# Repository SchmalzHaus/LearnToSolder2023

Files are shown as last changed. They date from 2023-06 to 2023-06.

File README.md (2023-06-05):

# LearnToSolder2018

Learn To Solder 2018 Board, assembled

## Introduction

For the past couple years, Deanna Schmalz has designed a simple circuit board which we then use to teach learn to solder classes. We  make enough boards and buy enough parts to teach all of the 4th graders at Glen Lake Elementary School in Minnetonka Minnesota, USA how to solder.

This site contains all of the information related to this year's Learn To Solder board. If you want to learn more about how to solder, if you want to know what you need to purchase so you can solder at home, or if you want to make more of these boards for yourself or your organization, this site has everything you'll need.

If you want to reach Brian Schmalz (brian@schmalzaus.com) or Deanna (deanna@schmalzhaus.com) to ask us any questions, please do so. 

All text files and designs on this site are Open Source. You are free to use these files and do whatever you wish with them.

## LearnToSolder 2018 Kit Contents

* Qty 1 Circuit Board - with pre-programmed PIC12F1572 CPU soldered on
* Qty 2 Switches
* Qty 2 Switch caps (various colors)
* Qty 2 Red LEDs
* Qty 2 Green LEDs
* Qty 2 Yellow LEDs
* Qty 2 Blue LEDs
* Qty 1 CR2032 Battery Holder
* Qty 1 CR2032 Battery
* Qty 2 random value through hole resistors (for Octopus eyebrows)

## Tools

To solder electronic kits together, you will need (at a minimum)

### Soldering Iron

We do not recommend buying a soldering iron unless it is 'temperature controlled'. This means you get to set the tip temperature with a knob or buttons, and the iron will only heat up as much as it needs to in order to maintain that temperature. Using a non-temp controlled iron has, in our experience, led to lots of frustration and failed kits.

This is the iron we recommend, as we've had great experience with it and it is very inexpensive : [http://www.hobbyking.com/hobbyking/store/__19240__Soldering_Station_with_Adjustable_Heat_Range_US_Warehouse_.html]

You can also by this same type of iron from many other places, including Amazon and Ebay, but the price tends to be a bit higher. Some of the companies listed below under Other Soldering Kits also sell tools like irons.

### Solder

For beginners, we strongly recommend using leaded solder (rather than lead-free). The safety risk is very minimal (just be sure to wash your hands with soap when you are done) and it is far, far easier to get good soldered joints with leaded solder when you're just starting to learn soldering. You can buy leaded electronic solder at many on-line stores like SparkFun [https://www.sparkfun.com/products/9161] or Adafruit [https://www.adafruit.com/products/1886]. Make sure to buy 60/40 or 63/37 (those numbers represent the ratio of tin to lead in the solder) electronic solder - there are other solders out there (like silver solder for jewelry for example) that won't work for electronics.

### Brass Sponge

When you buy your iron, buy a bras sponge if the iron doesn't already come with it. These are much better than the watter sponge that comes with the iron for cleaning the tip of the soldering iron.

### Wire Cutter

All of the companies listed below sell small wire cutters, or you can get them locally at hardware stores too. The best kind is something that will allow you to cut off wires flush with the board - sometimes called 'flush cutters'. For example [https://www.sparkfun.com/products/11952] or [https://www.adafruit.com/products/152]

### Other tools

There are lots of other tools you can get to help you while solder. Third-hands can be very useful. Needle nose pliers, solder suckers, magnifying glasses, solder wick, wire strippers, etc.

## Kit Assembly Process (overview)

There are only a couple steps to assembling this kit, as it is very simple. If you have done soldering before, you can just walk through this overview of the steps to complete your kit. If you want to learn more about how to do the actual soldering of a joint, the following websites and resources will give you plenty of background materials and explanations:

https://learn.sparkfun.com/tutorials/how-to-solder---through-hole-soldering

http://www.howtogeek.com/63630/how-to-use-a-soldering-iron-a-beginners-guide/

https://cdn-learn.adafruit.com/downloads/pdf/adafruit-guide-excellent-soldering.pdf

### Steps:

1. Solder the eight LEDs. Follow the color guide on the circuit board. Long lead (wire) goes into square hole. You sometimes have to wiggle the LEDs a bit to get them to press all the way flat down on the top side of the board due to a thick spot on the LED leads. Bend the leads apart on the back side to keep the LEDs in place as you solder the LED wires on the back side of the board. Clip the excess leads on the back of the board once soldered.

2. Insert the two switches into the board. Make sure all parts go into the board from the top side (with the thick white lines) to the back side. The switches snap down into the board - you sometimes have to press them in hard to get them to snap. But be careful - sometimes the pins come somewhat bent and pressing them down hard will bend them further if all four are not in the holes as you press down. Solder the four pins of each switch on the back side of the board. Snap the two switch caps down on the switches.

3. Insert the battery holder to the front of the board, being careful to align the outline of the battery hold to the white outline on the top of the board (there is a square tab on the battery holder than needs to match up to the square tab part of the outline). While holding the battery holder into the board, flip it over and solder both pins.

4. Insert the two eyebrow resistors. They are not part of the circut but are just for looks. Bend each lead of the reisstor so that the leads go through the board and the resistor sits flush on the board. Solder the leads on the back side of the board and clip excess lead length.

4. Insert the battery into the holder, flat shiny + side up. Press the buttons to see your LEDs light. If you hold down a button, the octopus will display a pattern.

## Other Soldering Kits

There are SO MANY kits available today, it's impossible to list all of them, or even the good ones. If you do a Google search for "electronic soldering kit" you will find lots of them out there. Some are easier than others, and some come with great instructions (and some don't).

We buy a lot of high quality soldering kits from the following on-line companies:

Evil Mad Scientist [http://shop.evilmadscientist.com/]
* Their Boldport Buggy is excellent [http://shop.evilmadscientist.com/]
* The Flickery Flame is a great beginner kit [http://shop.evilmadscientist.com/productsmenu/793]

Spark Fun Electronics [https://www.sparkfun.com/]
* They have a whole catagory of 'kits', some of which are soldering kits [https://www.sparkfun.com/categories/157]
* The SparkFun Simon Says - Through-Hole kit is really fun [https://www.sparkfun.com/products/10547]

Adafruit [https://www.adafruit.com/]
* The Drawdio is quite fun [https://www.adafruit.com/categories/28]
* Their Minty Boost is actually quite useful [https://www.adafruit.com/products/14]

SeeedStudio [http://www.seeedstudio.com/]
* Their 4-Soldering Zoo Kit looks super cute [https://www.seeedstudio.com/item_detail.html?p_id=1950]

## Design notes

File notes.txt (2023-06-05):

LearnToSolder 2018 Notes file

* Use PIC12F1572-I/SN microcontroller (8-pin SOIC SMT part)
* Use 2 push button switches as input
* Can push button switches do wakeup? Or is a SPDT slide switch needed? Looks like the two push buttons can be used to wake up the processor.
* How many LEDs can be chaliplexed? Wikipedia says up to 12 with 4 I/Os.
* Can we use RGB leds? (four pins)
  * Problem - their pins are very close together
* How about 8 LEDs (two each red, green, yellow, blue)?
* Need to add pads for programming/debugging - use 3D printed jig with pogo pins? How about 'snap-on' or 'clip on' to edge of board?

* What is best maximum board size?
  Seeed will do 100mm x 100mm, qt 10 for $4.41. But if qty goes up, price goes up. Order lots of 10s? Does that just increase shipping?

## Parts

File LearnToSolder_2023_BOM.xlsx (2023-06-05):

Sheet: Sheet1
Learn To Solder 2023 Octopus BOM
Qty | Ref | Description | Mfg Part Number | Distributor Part Number | Distributor
1 |  | Linear Voltage Regulator IC Positive Fixed 1 Output 1A SOT-223-4 | LM3940IMP-3.3/NOPB | LM3940IMP-3.3/NOPBCT-ND | Digikey
1 |  | USB-C (USB TYPE-C) USB 2.0 Receptacle Connector 24 (16+8 Dummy) Position Surface Mount, Right Angle; Through Hole | DX07S016JA1R1500 | 670-DX07S016JA1R1500TR-ND | Digikey
 |  | Connector Header Surface Mount, Right Angle 36 position 0.100" (2.54mm) | GEC36SBSN-M89 | S1113E-36-ND | Digikey
 | DO NOT POPULATE

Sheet: Sheet2
Pin | Number | Use | Left | 33 | Need: | 20 for motor drivers | SLEEP
RH2 | 1 | JP2 IO | LATCH |  |  | 6 for MISC | MS1
RH3 | 2 | JP2 IO | DIG_1 |  | Leavs: | 7 spare | MS2
RE1 | 3 | MS2_1 | DIG_2 |  |  |  | PFD
RE0 | 4 | MS1_1 | PRG | RC2 |  |  | ENABLE
RG0 | 5 | DIG_1 | USR_LED | RC1
RG1 | 6 | TX2 | USB_LED | RC0
RG2 | 7 | RX2
RG3 | 8 | DIG_2
MCLR | 9 | MCLR
RG4 | 10 | SPARE1
VSS | 11 | PWR
VDDCORE/VCAP | 12 | PWR
RF7 | 13 | PFD_4
RF6 | 14 | PFD_3
RF5 | 15 | PFD_2
RF4 | 16 | D+
RF3 | 17 | D-
RF2 | 18 | PFD_1
RH7 | 19 | JP2 IO
RH6 | 20 | JP2 IO
RH5 | 21 | JP2 IO
RH4 | 22 | JP2 IO
VUSB | 23 | PWR
ENVREG | 24 | PWR
AVDD | 25 | PWR
AVSS | 26 | PWR
RA3 | 27 | SPARE2
RA2 | 28 | SPARE3
RA1 | 29 | SPARE4
RA0 | 30 | SPARE5
VSS | 31 | PWR
VDDCORE/VCAP | 32 | PWR
RA5 | 33 | SPARE6
RA4 | 34 | LATCH
RC1 | 35 | JP1 IO
RC0 | 36 | JP1 IO
RC6 | 37 | JP1 IO
RC7 | 38 | JP1 IO
RJ4 | 39 | ENABLE_1
RJ5 | 40 | ENABLE_2
RJ6 | 41 | ENABLE_3
RJ7 | 42 | ENABLE_4
RC2 | 43 | JP1 IO
RC3 | 44 | JP1 IO
RC4 | 45 | JP1 IO
RC5 | 46 | JP1 IO
RB7 | 47 | DIR_4
VDD | 48 | PWR
OSC1 | 49 | -
OSC2 | 50 | -
VSS | 51 | PWR
RB6 | 52 | STEP_4
RB5 | 53 | DIR_3
RB4 | 54 | STEP_3
RB3 | 55 | DIR_2
RB2 | 56 | STEP_2
RB1 | 57 | DIR_1
RB0 | 58 | STEP_1
RJ3 | 59 | SLEEP_4
RJ2 | 60 | SLEEP_3
RJ1 | 61 | SLEEP_2
RJ0 | 62 | SLEEP_1
RD7 | 63 | SS
RD6 | 64 | SCK
RD5 | 65 | SDI_IN
RD4 | 66 | SDO_OUT
RD3 | 67 | SPARE7
RD2 | 68 | PRG
RD1 | 69 | USR_LED
VSS | 70 | PWR
VDD | 71 | PWR
RD0 | 72 | USB_LED
RE7 | 73 | MS2_4
RE6 | 74 | MS1_4
RE5 | 75 | MS2_3
RE4 | 76 | MS1_3
RE3 | 77 | MS2_2
RE2 | 78 | MS1_2
RH0 | 79 | JP2 IO
RH1 | 80 | JP2 IO

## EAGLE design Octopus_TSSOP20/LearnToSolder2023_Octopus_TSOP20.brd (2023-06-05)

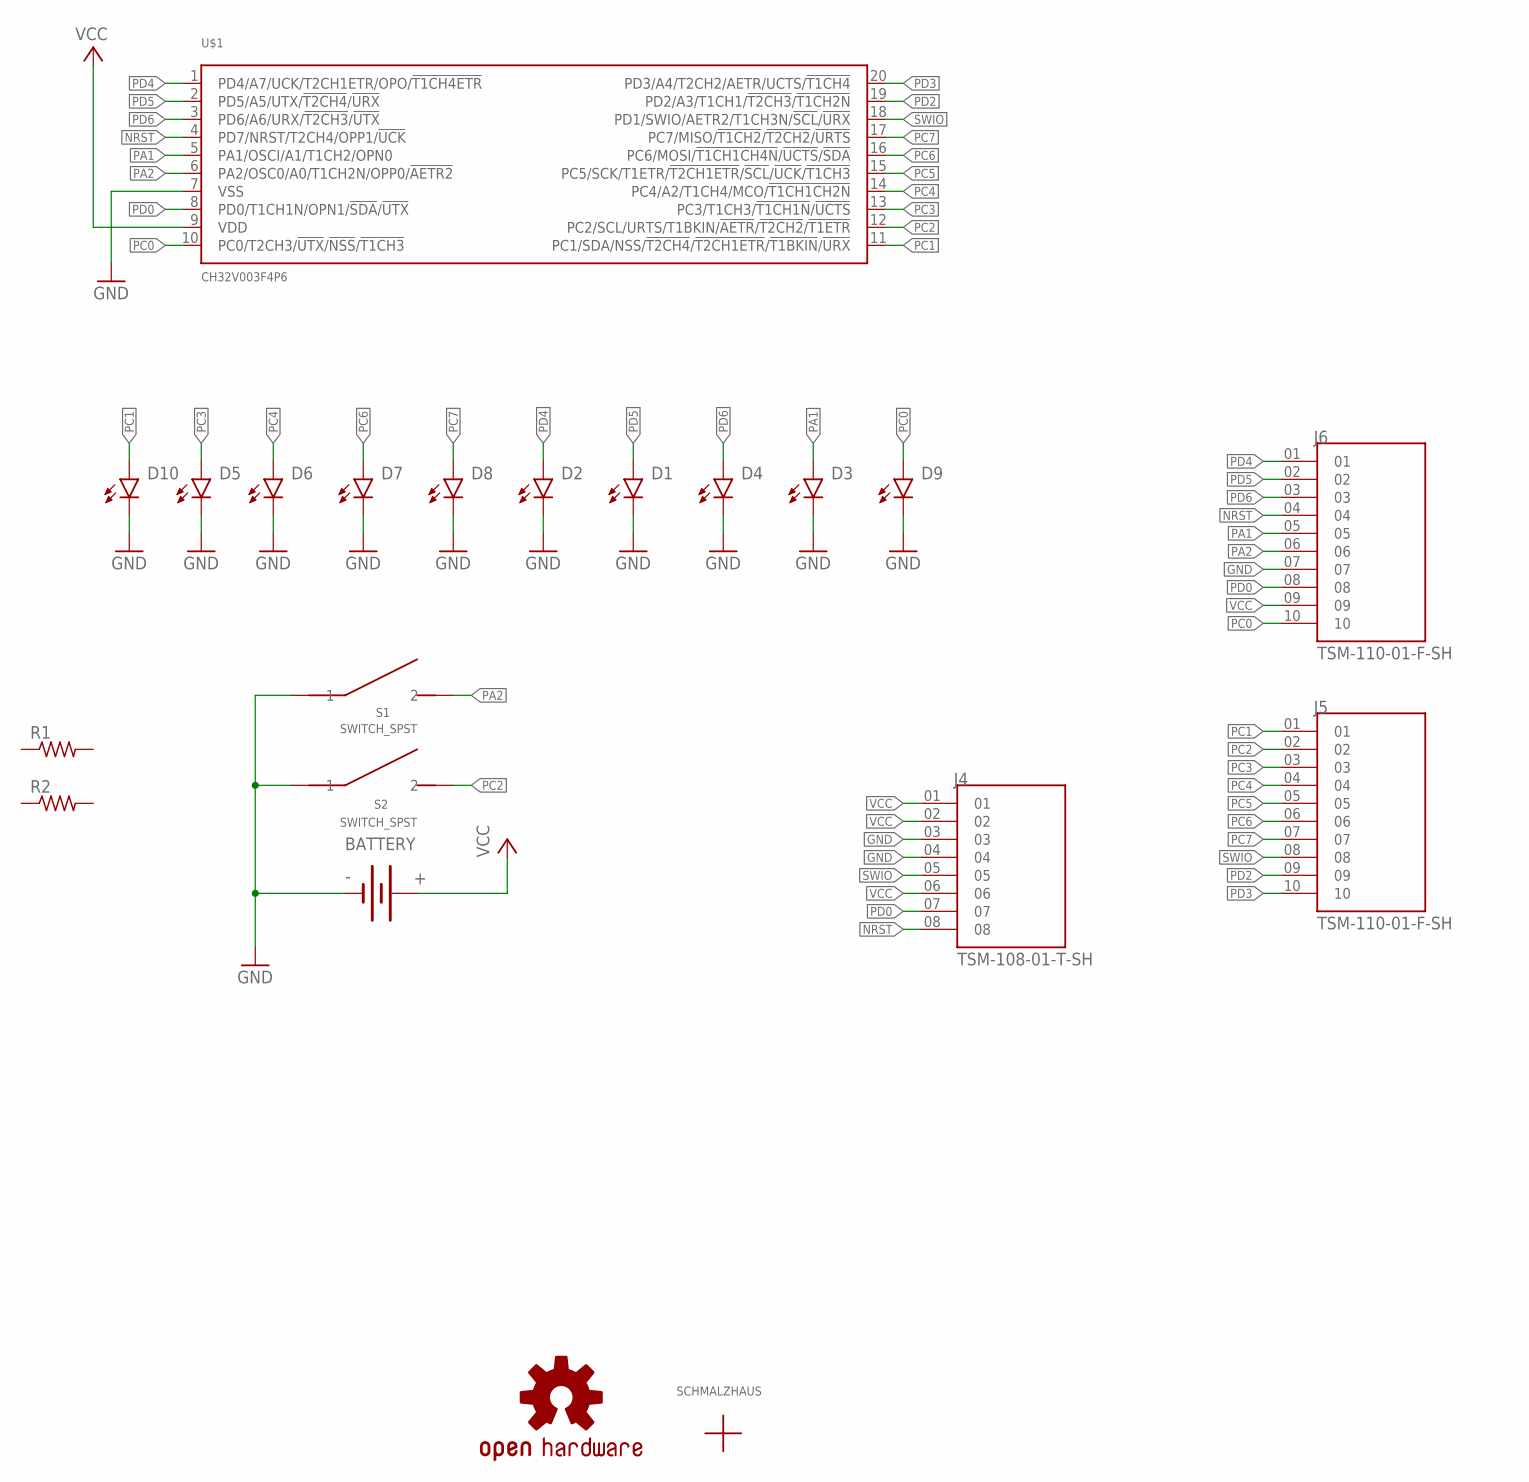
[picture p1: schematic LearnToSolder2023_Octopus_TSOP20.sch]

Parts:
BATTERY: BATTERY20PTH; BATTCOM_20MM_PTH
D1, D2, D3, D4, D5, D6, D7, D8, D9, D10: LED5MM
J4: TSM-108-01-T-SH; SAMTEC_TSM-108-01-T-SH
J5, J6: TSM-110-01-F-SH; SAMTEC_TSM-110-01-F-SH
LOGO1: OSHW-LOGOMINI; OSHW-LOGO-MINI
R1, R2: R-US_0309/12; 0309/12
S1, S2: SWITCH_SPST; OMRON-12MMX12MM_SPST-B3F-4000
U$1: CH32V003F4P6; TSSOP20
U$3: SCHMALZHAUSSCHMALZHAUS_SMALL; SCHMALZHAUS_SMALL

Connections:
GND: BATTERY.2 (-), D1.K (C), D2.K (C), D3.K (C), D4.K (C), D5.K (C), D6.K (C), D7.K (C), D8.K (C), D9.K (C), D10.K (C), J4.03, J4.04, J6.07, S1.1, S1.2 (1), S2.1, S2.2 (1), U$1.7 (VSS)
NRST: J4.08, J6.04, U$1.4 (PD7/NRST/T2CH4/OPP1/!UCK!)
PA1: D3.A, J6.05, U$1.5 (PA1/OSCI/A1/T1CH2/OPN0)
PA2: J6.06, S1.3 (2), S1.4 (2), U$1.6 (PA2/OSC0/A0/T1CH2N/OPP0/!AETR2!)
PC0: D9.A, J6.10, U$1.10 (PC0/T2CH3/!UTX!/!NSS!/!T1CH3!)
PC1: D10.A, J5.01, U$1.11 (PC1/SDA/NSS/!T2CH4!/!T2CH1ETR!/!T1BKIN!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)
PC2: J5.02, S2.3 (2), S2.4 (2), U$1.12 (PC2/SCL/URTS/T1BKIN/!AETR!/!T2CH2!/!T1E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)
PC3: D5.A, J5.03, U$1.13 (PC3/T1CH3/!T1CH1N!/!UCTS!)
PC4: D6.A, J5.04, U$1.14 (PC4/A2/T1CH4/MCO/!T1CH1CH2N!)
PC5: J5.05, U$1.15 (PC5/SCK/T1ETR/!T2CH1ETR!/!SCL!/!UCK!/!T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)
PC6: D7.A, J5.06, U$1.16 (PC6/MOSI/!T1CH1CH4N!/!UCTS!/!SDA!)
PC7: D8.A, J5.07, U$1.17 (PC7/MISO/!T1CH2!/!T2CH2!/!URTS!)
PD0: J4.07, J6.08, U$1.8 (PD0/T1CH1N/OPN1/!SDA!/!UTX!)
PD2: J5.09, U$1.19 (PD2/A3/T1CH1/!T2CH3!/!T1CH2N!)
PD3: J5.10, U$1.20 (PD3/A4/T2CH2/AETR/UCTS/!T1CH4!)
PD4: D2.A, J6.01, U$1.1 (PD4/A7/UCK/T2CH1ETR/OPO/!T1CH4ETR!)
PD5: D1.A, J6.02, U$1.2 (PD5/A5/UTX/!T2CH4!/!URX!)
PD6: D4.A, J6.03, U$1.3 (PD6/A6/URX/!T2CH3!/!UTX!)
SWIO: J4.05, J5.08, U$1.18 (PD1/SWIO/AETR2/T1CH3N/!SCL!/!URX!)
VCC: BATTERY.1 (+), J4.01, J4.02, J4.06, J6.09, U$1.9 (VDD)

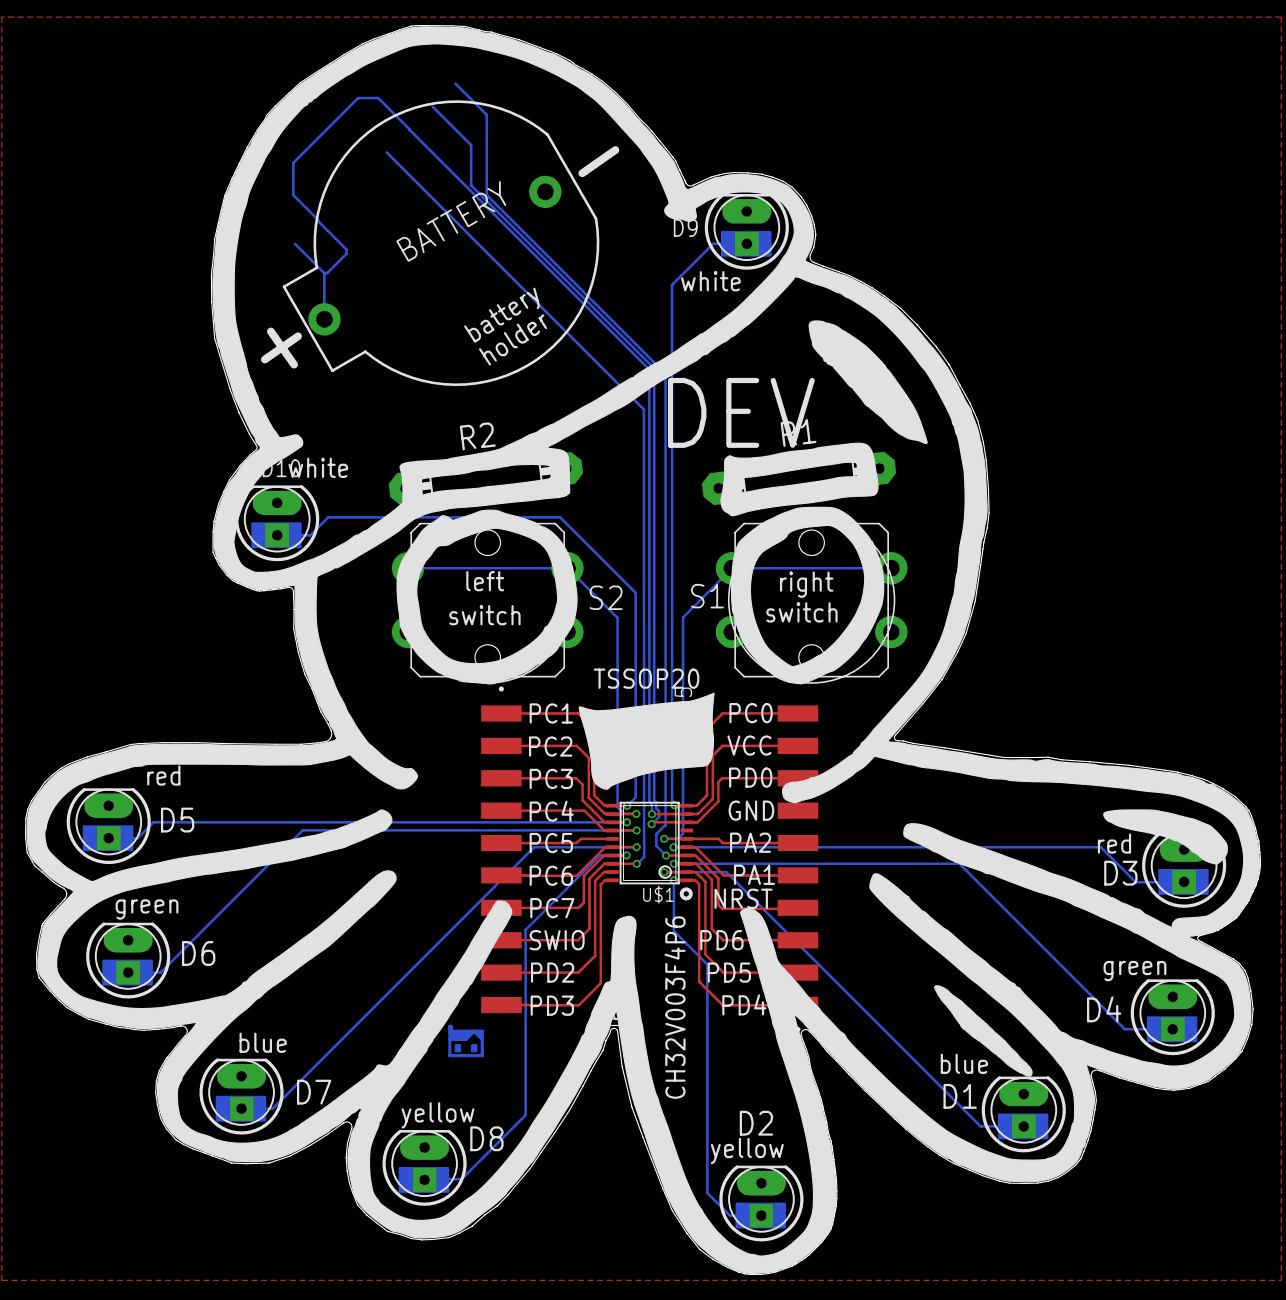
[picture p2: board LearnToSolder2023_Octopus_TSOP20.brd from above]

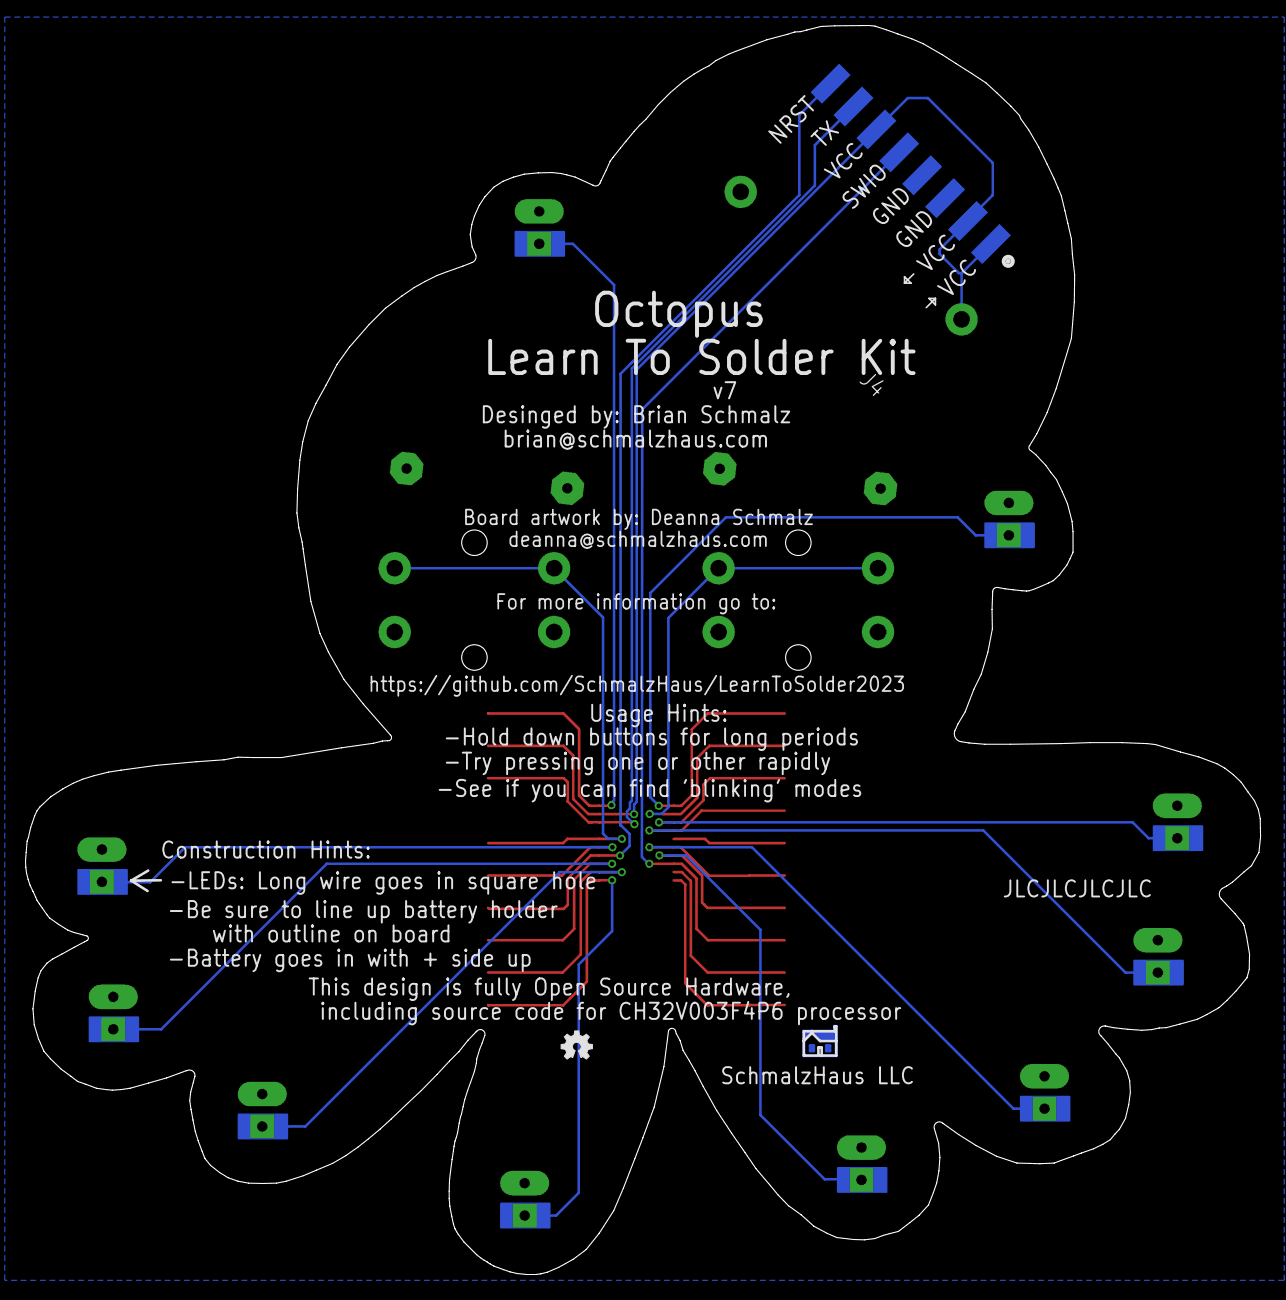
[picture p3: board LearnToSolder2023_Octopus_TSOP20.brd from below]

Board: 2 copper layers, 96.9 x 97.9 mm, 21 parts (3 on the bottom side), 20 nets.

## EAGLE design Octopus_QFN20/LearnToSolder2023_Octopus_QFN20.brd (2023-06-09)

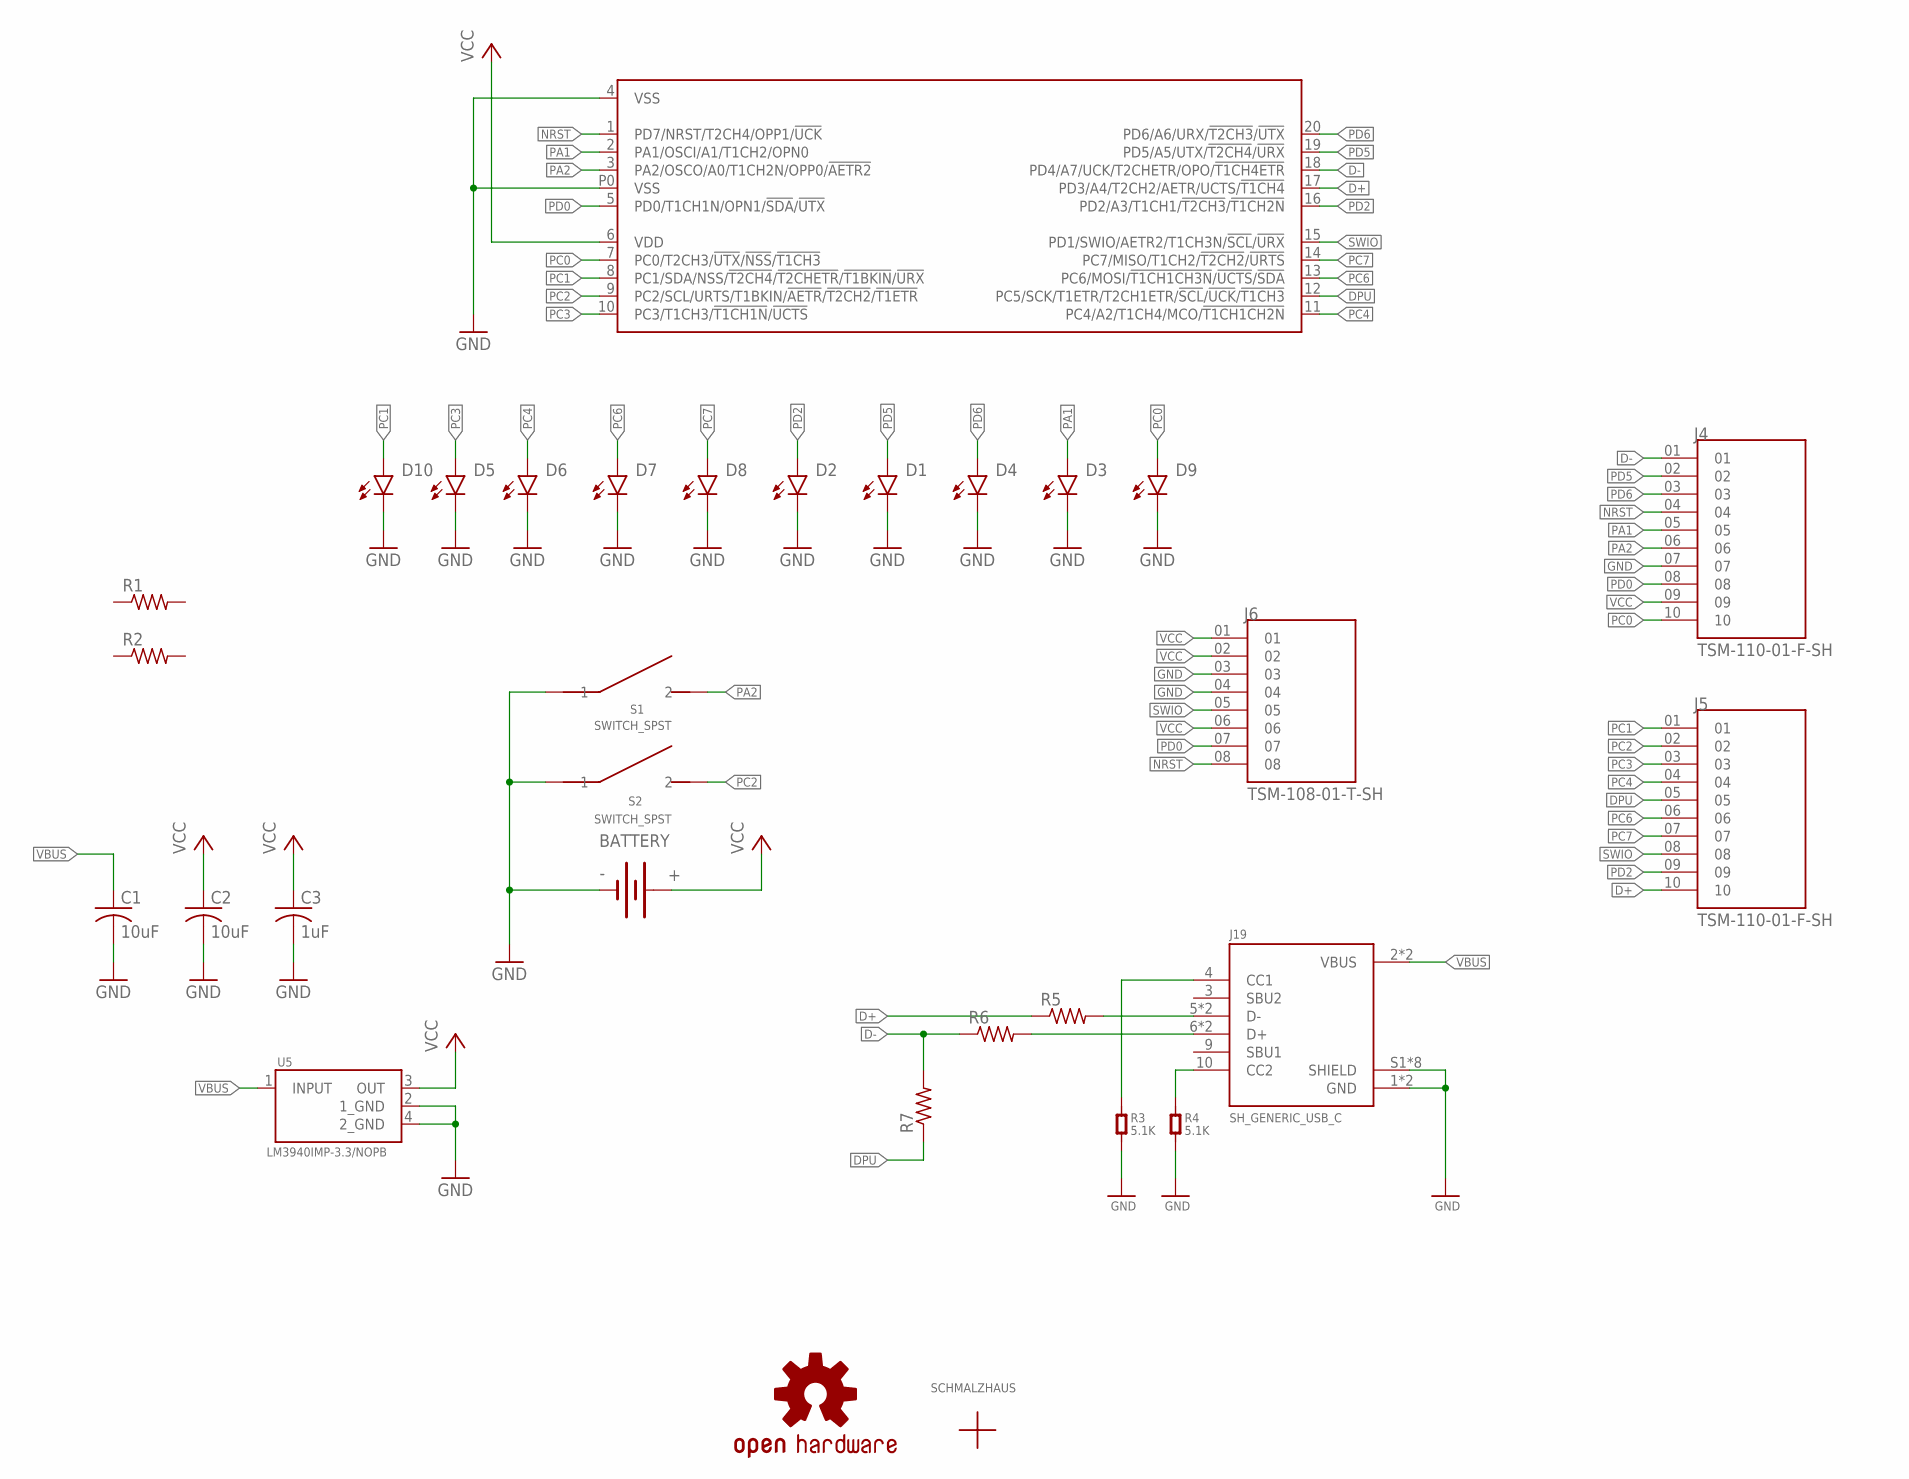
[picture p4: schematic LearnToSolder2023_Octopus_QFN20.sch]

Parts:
BATTERY: BATTERY20PTH; BATTCOM_20MM_PTH
C1, C2: 10uF; C0603
C3: 1uF; C0603
D1, D2, D3, D4, D5, D6, D7, D8, D9, D10: LED5MM
J4, J5: TSM-110-01-F-SH; SAMTEC_TSM-110-01-F-SH
J6: TSM-108-01-T-SH; SAMTEC_TSM-108-01-T-SH
J19: SH_GENERIC_USB_C
LOGO1: OSHW-LOGOMINI; OSHW-LOGO-MINI
R1, R2: R-US_0309/12; 0309/12
R3, R4: 5.1K; R0603
R5, R6, R7: R-US_R0603; R0603
S1, S2: SWITCH_SPST; OMRON-12MMX12MM_SPST-B3F-4000
U5: TEXAS_INSTRUMENTS_LM3940IMP-3_3-NOPBTEXAS_INSTRUM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; TEXAS_INSTRUMENTS_LM3940IMP-3_3-NOPB_0
U$1: CH32V003F4U6; QFN20
U$3: SCHMALZHAUSSCHMALZHAUS_SMALL; SCHMALZHAUS_SMALL

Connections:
D+: J5.10, R5.1, U$1.17 (PD3/A4/T2CH2/AETR/UCTS/!T1CH4!)
D-: J4.01, R6.1, R7.2, U$1.18 (PD4/A7/UCK/T2CHETR/OPO/!T1CH4ETR!)
DPU: J5.05, R7.1, U$1.12 (PC5/SCK/T1ETR/T2CH1ETR/!SCL!/!UCK!/!T1C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)
GND: BATTERY.2 (-), C1.2, C2.2, C3.2, D1.K (C), D2.K (C), D3.K (C), D4.K (C), D5.K (C), D6.K (C), D7.K (C), D8.K (C), D9.K (C), D10.K (C), J4.07, J6.03, J6.04, J19.1 (GND), J19.12 (GND), J19.S1 (SHIELD), J19.S2 (SHIELD), J19.S3 (SHIELD), J19.S4 (SHIELD), J19.S5 (SHIELD), J19.S6 (SHIELD), J19.S7 (SHIELD), J19.S8 (SHIELD), R3.1, R4.1, S1.1, S1.2 (1), S2.1, S2.2 (1), U5.2 (1_GND), U5.4 (2_GND), U$1.4 (VSS), U$1.P0 (VSS)
unnamed: J19.4 (CC1), R3.2
unnamed: J19.10 (CC2), R4.2
unnamed: J19.5 (D-), J19.7 (D-), R5.2
unnamed: J19.6 (D+), J19.8 (D+), R6.2
NRST: J4.04, J6.08, U$1.1 (PD7/NRST/T2CH4/OPP1/!UCK!)
PA1: D3.A, J4.05, U$1.2 (PA1/OSCI/A1/T1CH2/OPN0)
PA2: J4.06, S1.3 (2), S1.4 (2), U$1.3 (PA2/OSCO/A0/T1CH2N/OPP0/!AETR2!)
PC0: D9.A, J4.10, U$1.7 (PC0/T2CH3/!UTX!/!NSS!/!T1CH3!)
PC1: D10.A, J5.01, U$1.8 (PC1/SDA/NSS/!T2CH4!/!T2CHETR!/!T1BKIN!/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)
PC2: J5.02, S2.3 (2), S2.4 (2), U$1.9 (PC2/SCL/URTS/T1BKIN/!AETR!/!T2CH2!/!T1E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)
PC3: D5.A, J5.03, U$1.10 (PC3/T1CH3/!T1CH1N!/!UCTS!)
PC4: D6.A, J5.04, U$1.11 (PC4/A2/T1CH4/MCO/!T1CH1CH2N!)
PC6: D7.A, J5.06, U$1.13 (PC6/MOSI/!T1CH1CH3N!/!UCTS!/!SDA!)
PC7: D8.A, J5.07, U$1.14 (PC7/MISO/T1CH2/!T2CH2!/!URTS!)
PD0: J4.08, J6.07, U$1.5 (PD0/T1CH1N/OPN1/!SDA!/!UTX!)
PD2: D2.A, J5.09, U$1.16 (PD2/A3/T1CH1/!T2CH3!/!T1CH2N!)
PD5: D1.A, J4.02, U$1.19 (PD5/A5/UTX/!T2CH4!/!URX!)
PD6: D4.A, J4.03, U$1.20 (PD6/A6/URX/!T2CH3!/!UTX!)
SWIO: J5.08, J6.05, U$1.15 (PD1/SWIO/AETR2/T1CH3N/!SCL!/!URX!)
VBUS: C1.1, J19.2 (VBUS), J19.11 (VBUS), U5.1 (INPUT)
VCC: BATTERY.1 (+), C2.1, C3.1, J4.09, J6.01, J6.02, J6.06, U5.3 (OUT), U$1.6 (VDD)

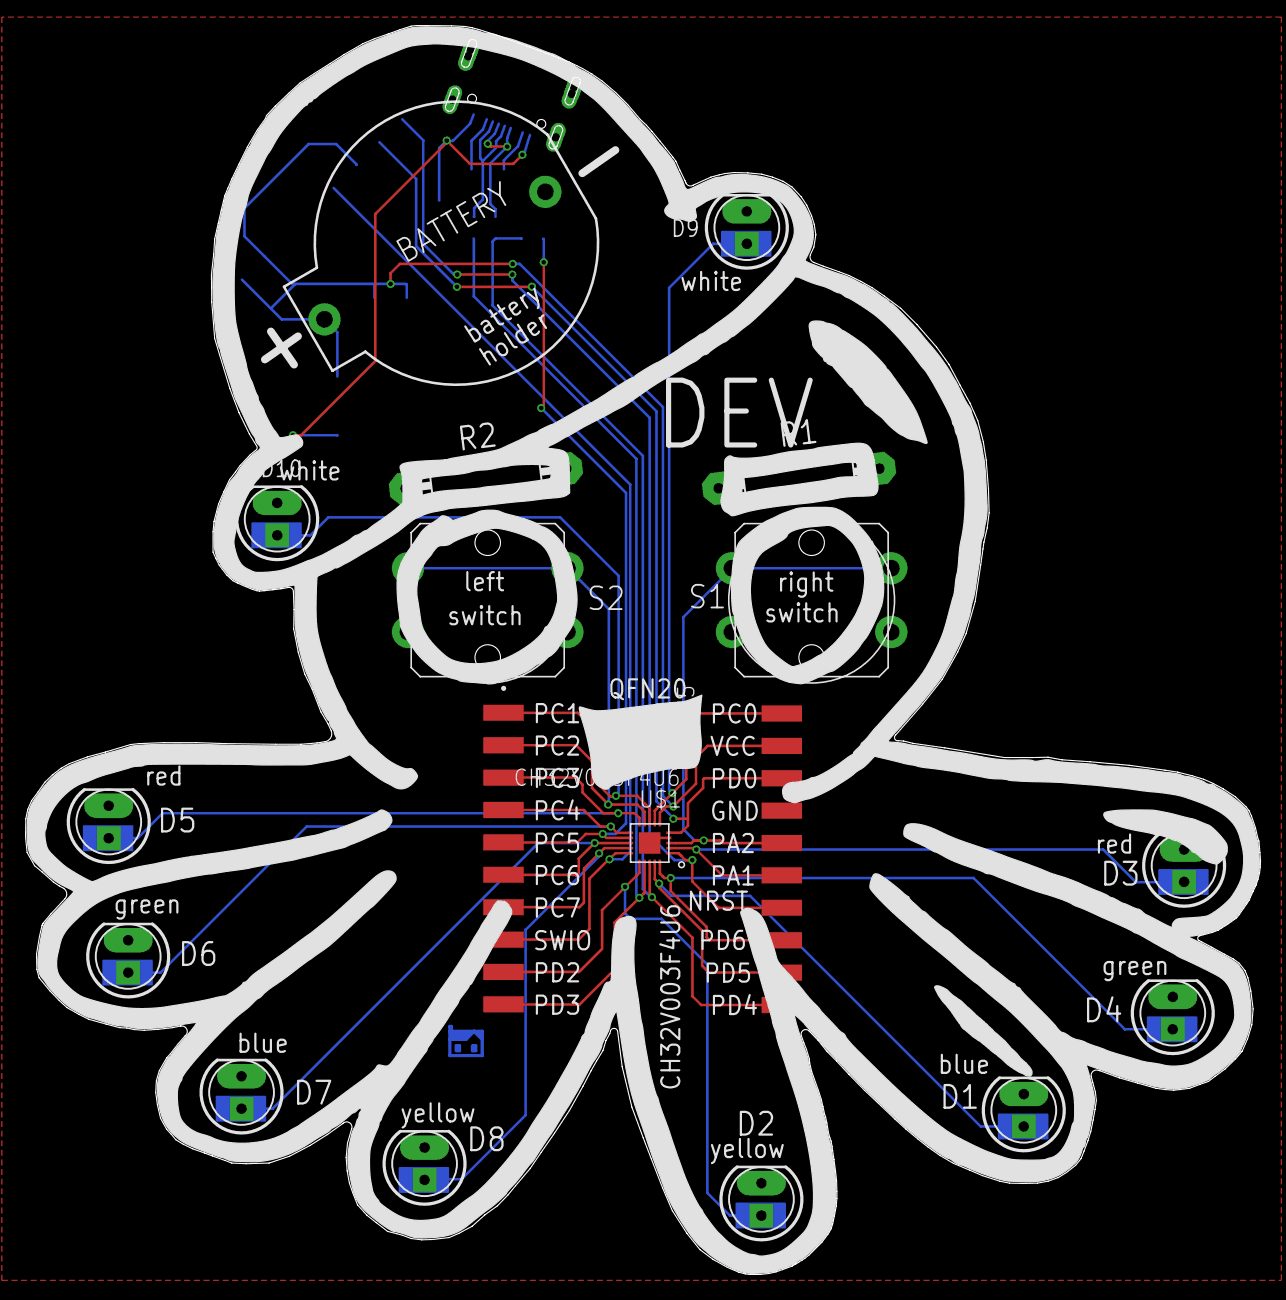
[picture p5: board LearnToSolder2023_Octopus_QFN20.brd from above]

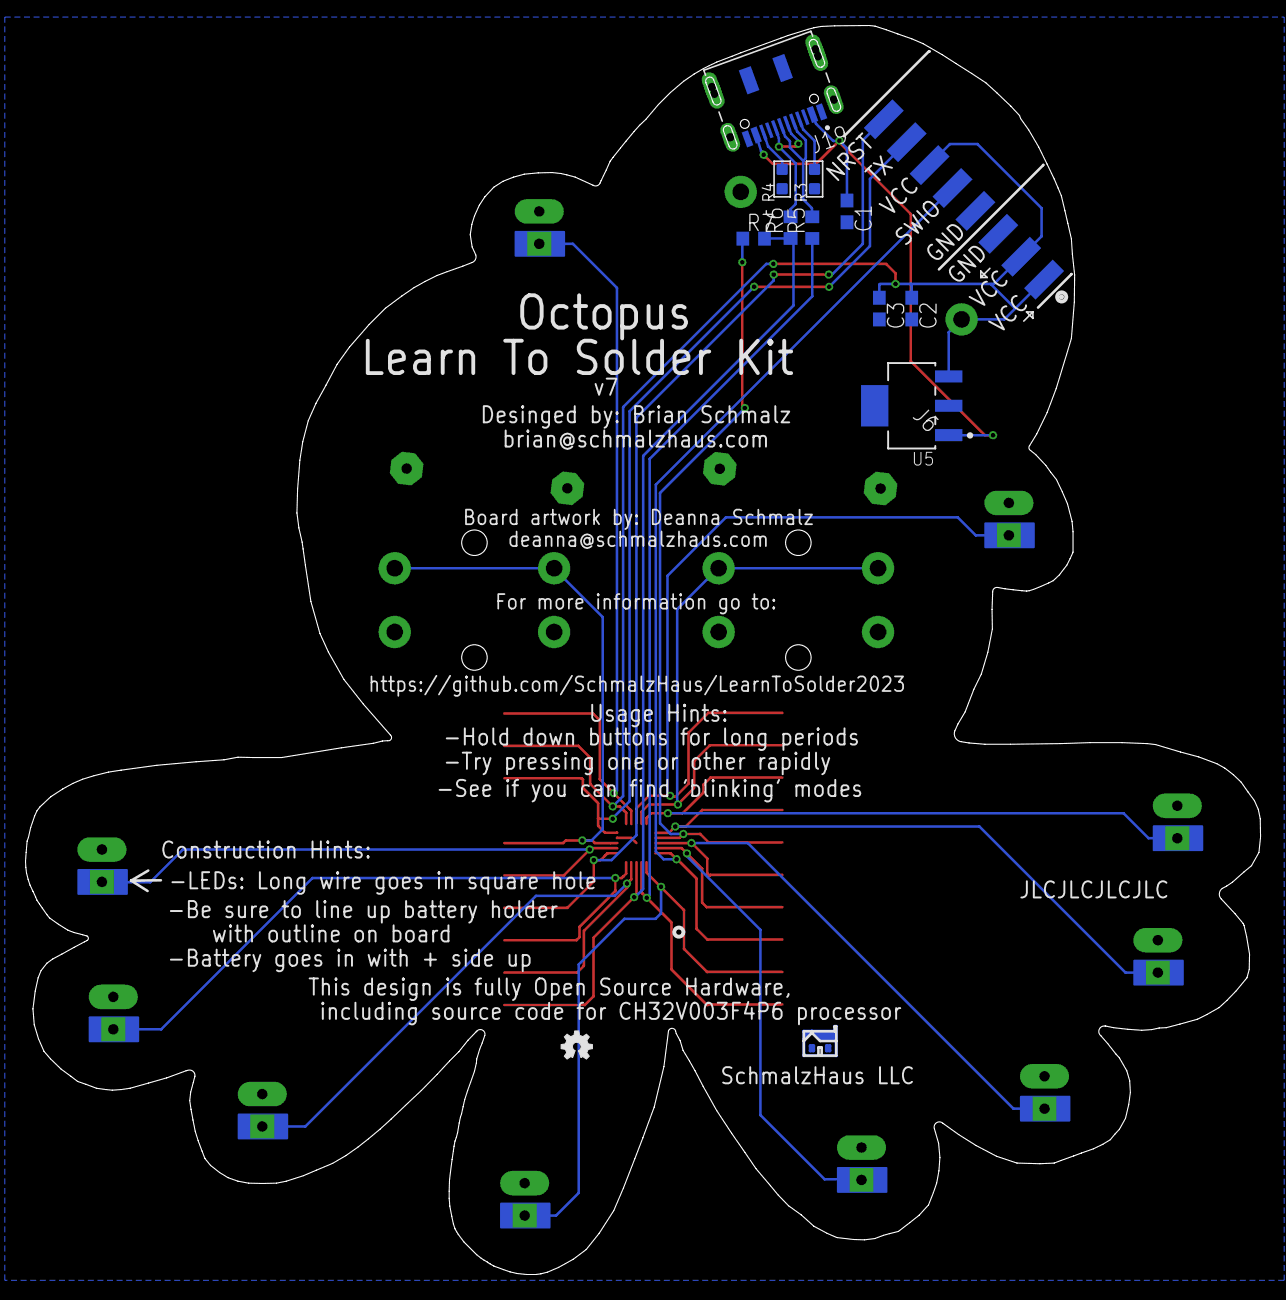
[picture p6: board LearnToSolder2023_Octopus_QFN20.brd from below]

Board: 2 copper layers, 96.9 x 97.9 mm, 31 parts (13 on the bottom side), 25 nets.

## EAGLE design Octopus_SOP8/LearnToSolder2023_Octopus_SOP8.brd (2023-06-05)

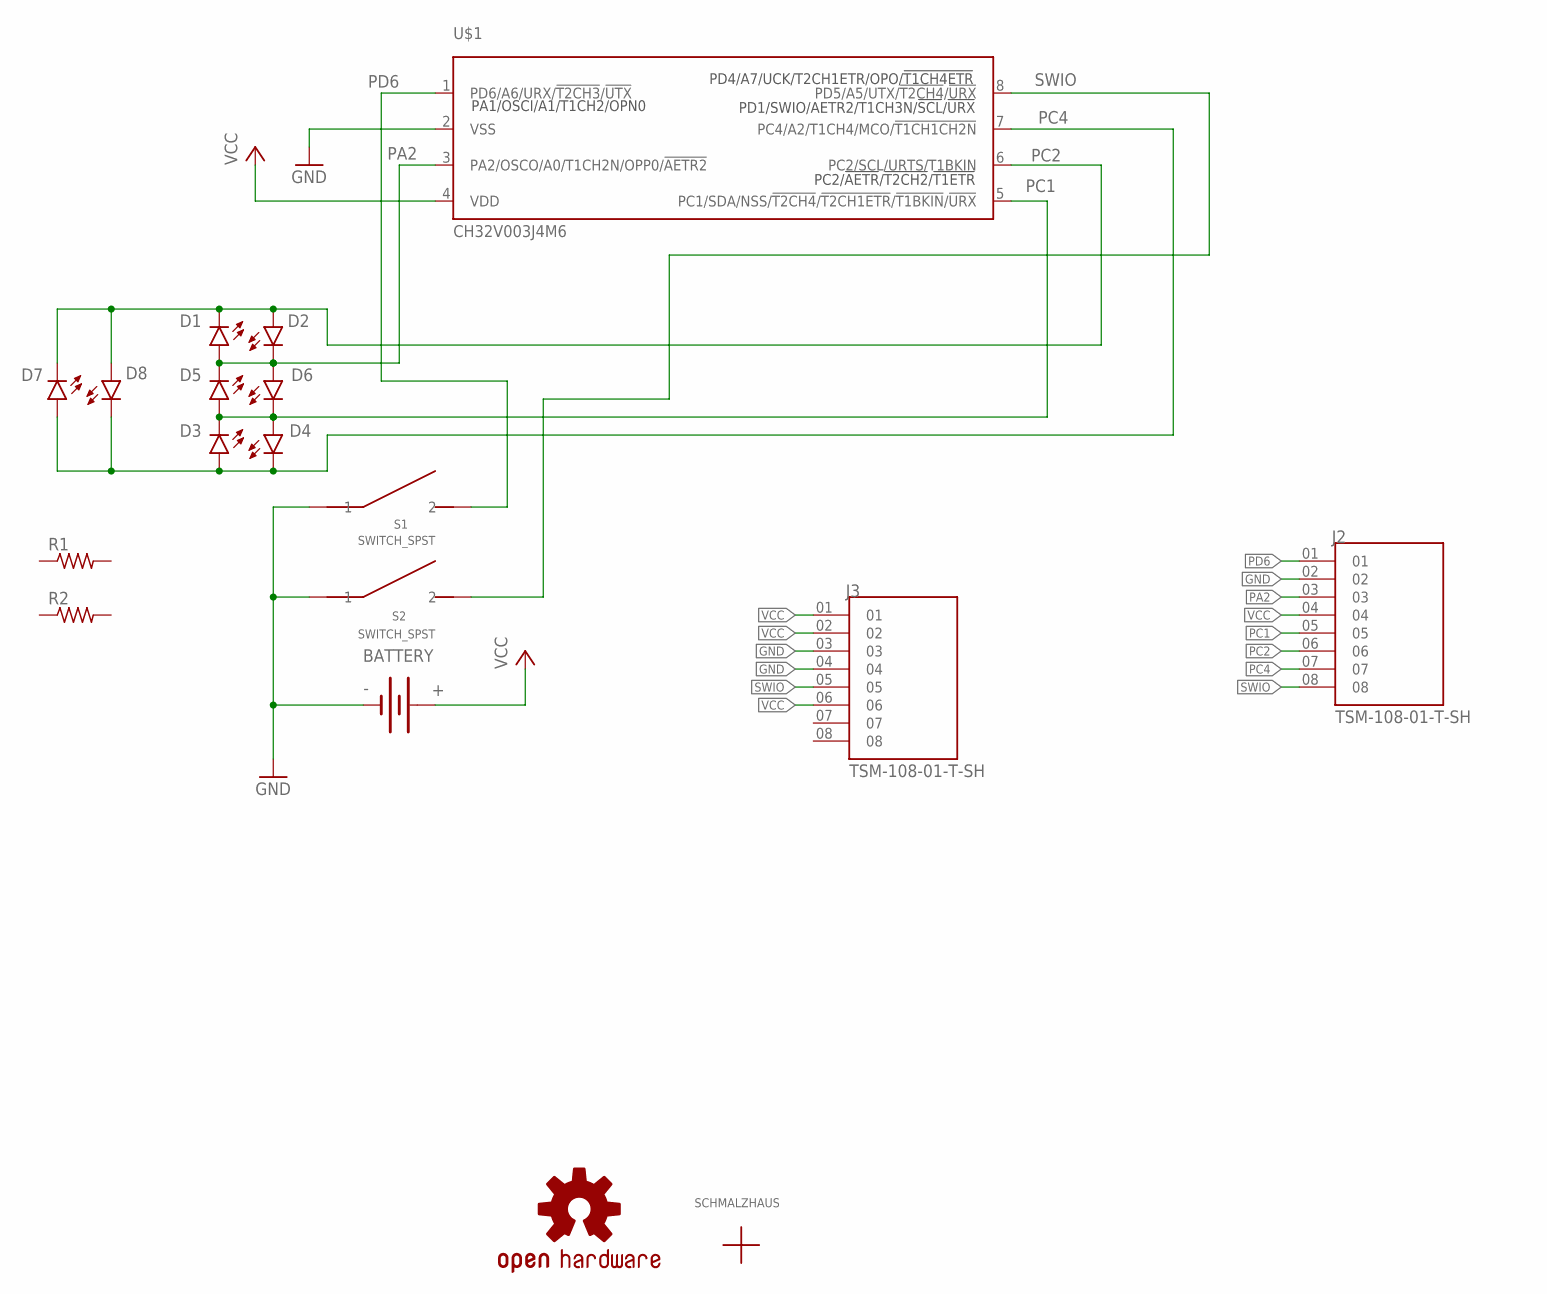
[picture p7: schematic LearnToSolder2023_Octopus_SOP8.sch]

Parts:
BATTERY: BATTERY20PTH; BATTCOM_20MM_PTH
D1, D2, D3, D4, D5, D6, D7, D8: LED5MM
J2, J3: TSM-108-01-T-SH; SAMTEC_TSM-108-01-T-SH
LOGO1: OSHW-LOGOMINI; OSHW-LOGO-MINI
R1, R2: R-US_0309/12; 0309/12
S1, S2: SWITCH_SPST; OMRON-12MMX12MM_SPST-B3F-4000
U$1: CH32V003J4M6; SOP8
U$3: SCHMALZHAUSSCHMALZHAUS_SMALL; SCHMALZHAUS_SMALL

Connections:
GND: BATTERY.2 (-), J2.02, J3.03, J3.04, S1.1, S1.2 (1), S2.1, S2.2 (1), U$1.2 (VSS)
PA2: D1.A, D2.K (C), D5.K (C), D6.A, J2.03, U$1.3 (PA2/OSCO/A0/T1CH2N/OPP0/!AETR2!)
PC1: D3.K (C), D4.A, D5.A, D6.K (C), J2.05, U$1.5 (PC1/SDA/NSS/!T2CH4!/!T2CH1ETR!/!T1BKIN!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)
PC2: D1.K (C), D2.A, D7.K (C), D8.A, J2.06, U$1.6 (PC2/SCL/URTS/T1BKIN)
PC4: D3.A, D4.K (C), D7.A, D8.K (C), J2.07, U$1.7 (PC4/A2/T1CH4/MCO/!T1CH1CH2N!)
PD6: J2.01, S1.3 (2), S1.4 (2), U$1.1 (PD6/A6/URX/!T2CH3!/!UTX!)
SWIO: J2.08, J3.05, S2.3 (2), S2.4 (2), U$1.8 (PD5/A5/UTX/!T2CH4!/!URX!)
VCC: BATTERY.1 (+), J2.04, J3.01, J3.02, J3.06, U$1.4 (VDD)

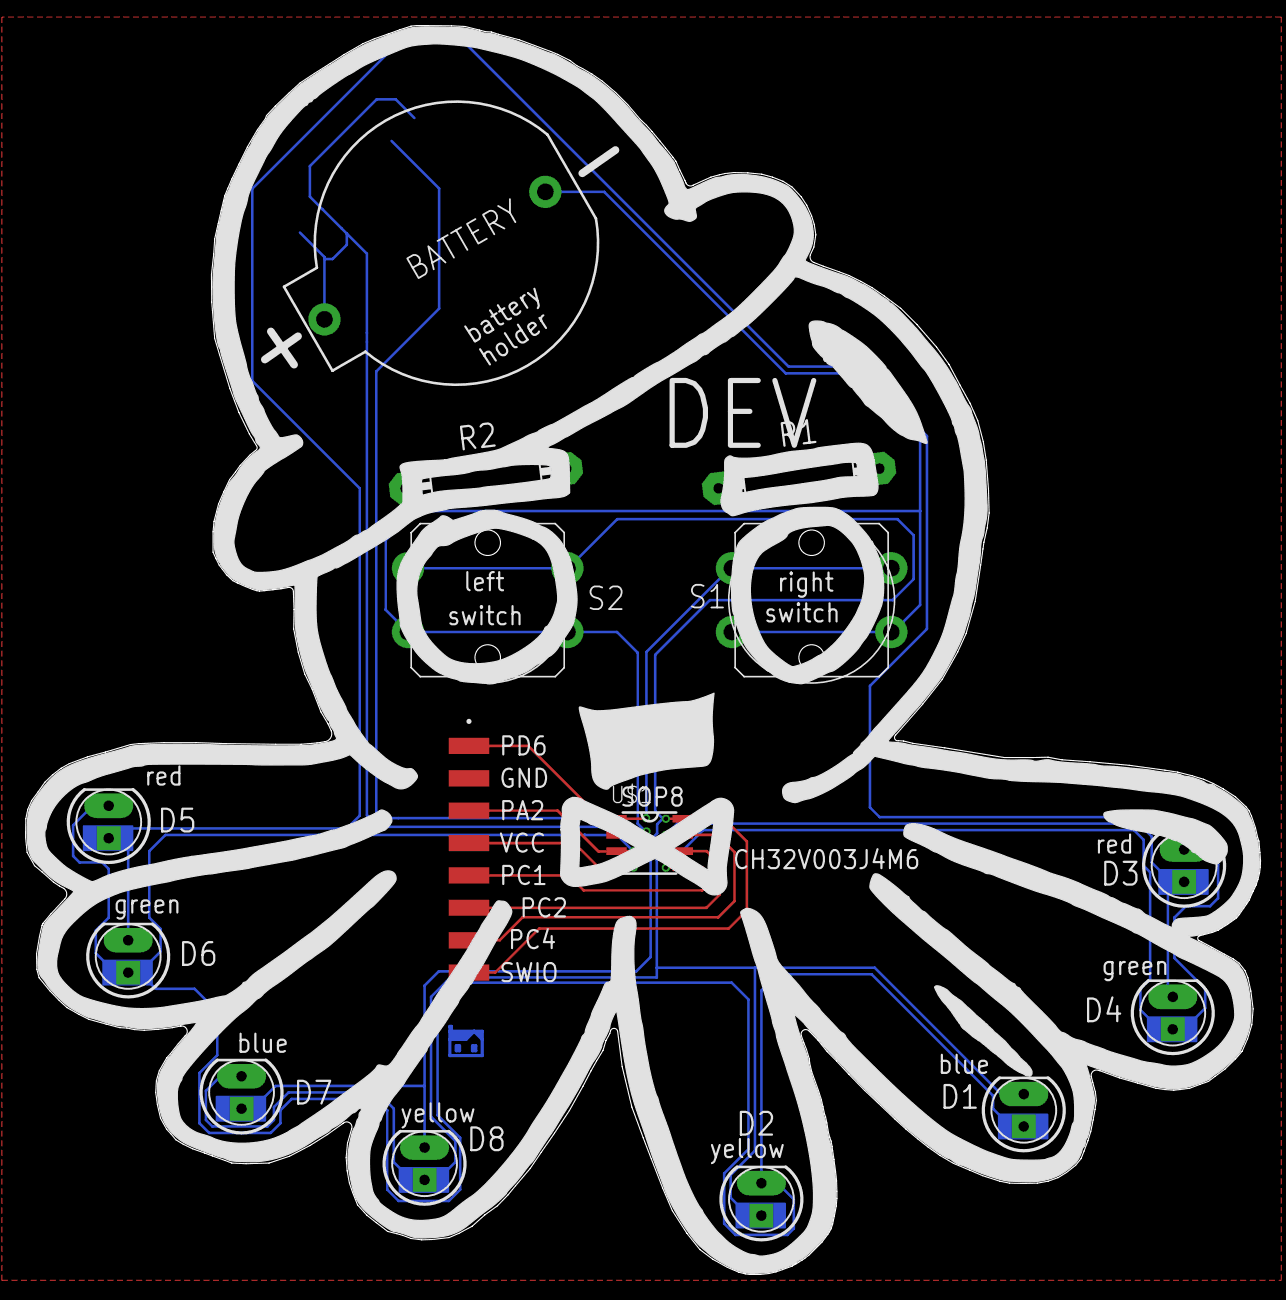
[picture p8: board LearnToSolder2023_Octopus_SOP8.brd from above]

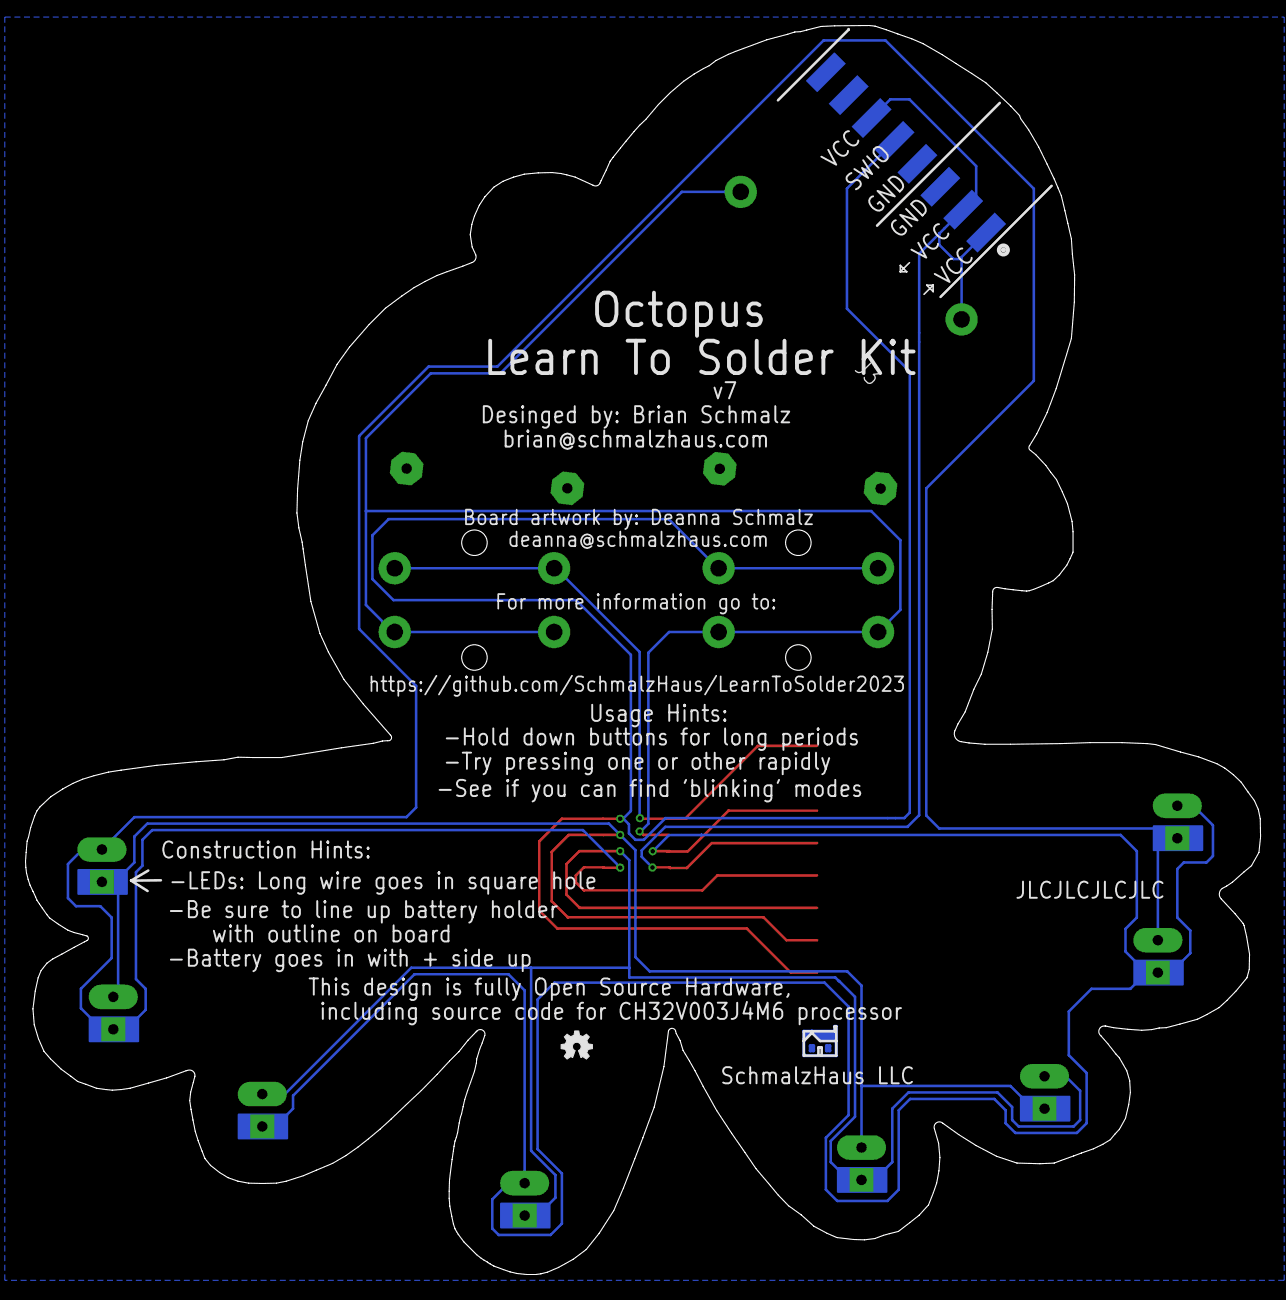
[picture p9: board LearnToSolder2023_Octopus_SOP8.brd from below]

Board: 2 copper layers, 96.9 x 97.9 mm, 18 parts (3 on the bottom side), 8 nets.

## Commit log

2023-06-05 First check in
    [LearnToSolder2023_Octopus_QFN20.brd, LearnToSolder2023_Octopus_QFN20.sch, LearnToSolder2023_Octopus_SOP16.brd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]
2023-06-09 Updated QFN20 footprint to be 3x3 rather than 5x5. Reworked Octopus QFN20 board.
    [LearnToSolder2023_Octopus_QFN20.brd, LearnToSolder2023_Octopus_QFN20.sch]
2023-06-19 Move everything into their own folders.
    [LearnToSolder2023_Octopus_QFN20.brd, LearnToSolder2023_Octopus_QFN20.sch, LearnToSolder2023_Octopus_SOP16.brd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]

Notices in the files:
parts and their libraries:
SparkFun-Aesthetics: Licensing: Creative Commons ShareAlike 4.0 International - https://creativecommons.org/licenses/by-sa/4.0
